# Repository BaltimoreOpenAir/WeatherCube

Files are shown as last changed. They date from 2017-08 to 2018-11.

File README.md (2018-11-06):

# WeatherCube
This repo provides code and schematics for the WeatherCube, an environmental monitoring platform used for the Baltimore OpenAir project. More info is on our project page at baltimoreopenair.github.io

#

# Hardware

## Circuit Boards 

### Component list:

1- The main board: It supports the microcontrollers. Its the brain of the device

2- Charging controller: provides power to the main board, charge up the battery with the solar panel

3- Lithium polymer battery: holds the power for the device

4- Analog front end board: holds the air quality sensors

5- Coin CR battery: powers the clock in case of loss of power

6- temperature sensor board: measures temperature and humidity in the tunnel

7- solar pannel: powers the unit

8- 4x air quality sensor: for N02,03,SO2 and H2S

9- 3X Molex picoblade cable assembly (2X 4 pins and 1X 5 pins): connects boards together

10- FTDI ttl/usb controller: allows to load code

11- ttl/usb ESP adapter: allows to connect the FTDI controller to load code in the ESP wifi chip

12- ttl/usb ATMEGA adapter: allows to connect the FTDI controller to load code in the ATMEGA microcontroller

## Electronic Assembly:

### Necessary equipment

1- Soldering iron

2- snips

3- box cutter

4- lead free rosin core solder of small gauge

5- a breadboard to serve as jig

6- A good multimeter for quality check

7- tweezers

9- a brush (such as a toothbrush)

10- methanol or rubbing alcohol

### Solder male header pins onto the main sensor board 

Use male 2.54mm (1/10th in) pitch headers. The headers come in 40 pins assembly, and will need to be sniped to the correct size. for this board you need 3x 7pins, 2x 2pins and 1x 1pin headers. You can use the ttl/usb adapter and/or a breadboard as jig to hold the pins in place at a right angle from the board. the pins should protrude in the front of the board and be soldered from the back. The positions of the headers are marked by yellow cirlces in the following image.

soldering of the 1/10th pitch headers on the main board (front of the board)

### Solder female header pins onto the Analog Front End (AFE) board
Use female 2mm pitch 2pin headers. You will need 12x 2pin headers. The pins should protrude from the front of the board and be soldered from the back. You can make a jig with 2mm male headers on a unassembled AFE PCB in order to correctly align the female headers. The pins should be scrubed with high proof methanol or other alcohol after soldering to avoid sensor bias. Resistance should be in excess of 40M Ohm between the reference and control electrode when the sensor is not mounted. The positions of the headers are marked by yellow cirlces in the following image. 

soldering of the 2mm pitch headers on the AFE board (front of the board)

### Solder the main sensor board to the solar charging board
The main board is to be soldered with the wires coming from the charge controller. If the battery is already soldered to the charge controller, you will be soldering live wires if the black and white wire connect. This does not constitute a danger of electrocution due to the low DC voltage but may lead to burining the charge controller if the board is shorted, and is a risk of fire. Therefore, extreme caution is necessary. The recommended order for soldering is red wire (5v) then the white wire ( enable wire). At this point, it is important to check that the red and white wires do not connect in any way, and trimming the wire ends may be a good idea. You can then solder the black wire (ground). Be careful not to short the circuit accidentally with the tip of your soldering iron. This closes the circuit. The positions of the wires are marked in the following image.

soldering of the wires on the main board

### Solder the usb/ttl adapters

The usb/ttl adapter need both male and female headers of 2.54mm pitch. The male headers are suposed to be protruding on the front of both boards and the female headers on the back. You may use a soldered main board as a jig to gold the female headers in place. To snip the female headers to the correct size, first count the numbers of pins you need and pull the next pin. You can then cut the header to sizer with a box cutter and shave the plastic for esthetics. The following image displat the positions of the male headers (yellow circles) and female headers (purple circles). For this, you need 2X 6pin male headers and 4X 7pin female headers. for the female headerds of the usb/ttl ESP adapter, you will need to pull some of the pins to fit in the soldering holes.

soldering headers on the usb/ttl atmega adapter

soldering headers on the usb/ttl esp adapter

### Plug things together
Follow the following figures to connect the differents component together. Do not forget to place the enable jumper on the main board once the code is loaded in

Connections on the main board

Connections on the Analog front end

## Sensors 
Read the calibration codes off the sensor QR codes using any QR code reader. Save these codes for later calibration. Then, plug in the sensors clockwise from the top left in the following order: O3, H2S, SO2, and NO2.

## Code loading

The software section describes the code that need to be loaded for the project. Here we describe the hardware setup necessary to communicate with the assembled device.

1- take the jumper off the enable pin on the main board.

2- connect the usb/ttl adapters on the wifi chip and on the atmega adapter.

3- make sure the FTDI controller jumper is on 3.3V

4- connect the FTDI controller with the usb cable to the computer. make sure that the ftdi controller has the proper driver installed. This can be done on windows by running this [executable](https://cdn.sparkfun.com/assets/learn_tutorials/7/4/CDM21228_Setup.exe).

5- connect the ftdi controller on the esp adapter.

6-  Using Arduino IDE, select the right com port and select the generic esp8266 in the tool section and load the esp8266 code. Make sure to modify the code with the target wifi credentials.

7- disconnect the FTDI controller and connect it to the atmega adapter. Using Arduino IDE, select the right com port and the arduino UNO board, load the code. You may have trouble to establish connections with the atmega when loading a code more than once. Restarting the computer seem to help in that case.

8- disconnect the adapters and put back the enable jumper. your weathercube is ready to be deployed!

## Hardware Quality checks

Using a multimeter one can check all the parameters of the device to check if all the component are working nominaly.

1- Check battery power: on the charge controller board, check the voltage potential at the soldered battery wires. The voltage should be between 2.8v and 4.2V. If close to 0V, check the battery wiring connections. If higher that 0.5V but lower than 2.8V, the battery is probably damaged. If higher than 4.2V the charge controller is damaged. If higher than 2.8V but lower than 3.3V, you should connect and charge the battery before usage using the mini usb port until reaching 4.2V.

2- Solar panel check: on the charge controller board, measure the voltage between the two wires of the solar panel. This should read between 4.1 and 4.4 V when the panel is exposed to direct sunlight. If the voltage is very low, there must be a problem in the wire connection on the solar panel. It the voltage is higher, the solar panel is runing in an open circuit, which means that either the battery is full, or if it is not, that the charge controller is damaged ore the solar panel wire connection on the charge controller is not good.

3- battery charge tester on the charge controller: click on the push button on the charge controller. If the charge controller leds do not light up and the battery voltage is superior to 2.8V this means that the charge controller is damaged.

4- main board power: check the voltage between the red and black wire of the charge controller on the main board. This should read close to 5V. if not the charge controller is damaged, or the connection of the white and black wire is not good. you can then check the volatege between vcc and ground on the board. it should read 3.3v when the enable pin is jumped and 0v else. If it reads 0V when the enable pin is in, the charge board is damaged or the connection is not good. if th reads 3.3V weither or not the jumper is on the enable pin, it means that the enable pin is shorted: check for solder residues that may short the two pins.

5- AFE board checks: the resistance between the 2mm pitch pins should be checked with a good multimeter (measurs resistance up to 40Mohm at least such as [this](https://www.amazon.com/dp/B000JKMTDM/ref=psdc_15707471_t2_B0050LVFS0)). Off the trio of headers for each sensor, the top one should have a resistance higher than 40Mohm when the sesor is not pluged in while the other should display no resistance. a 40Mohm reistance would bias the result by about 20ppb, which is the resolution of the sensor we are using. If the resistance is lower than that, pluck the plastic part of the pin and clean thourouly the plastic part and the pins with methanol. reassemble when dry and check again.

6- Fan check: in normal operation the fan should be runing every 15minutes for 30 seconds. If the fan does not run, you may try to run the fan by applying a 5v potential between its ground and live wires. Make sure you respect polarity. if the fan does not spin, it might be jammed. To unjam the fan, disasemble the air tunnel and manually check for fan rotation. take out any obstruction and check for rotation again. replace fan if need be.

7- Charging operation: check the battery volatage and note it up to 4 significant numbers. Put the weathercube in full sun for few hours. Without the main board unabled the unit should charge the battery at about .05V to .2V per hour in full unobstructed sun. The unit should still charge between .04V to .15V per hours when the unit is in operation. If not, the whole power circuit (solar panel, charging board and battery) might have to be recheched or replaced.

8- Com operation: when the cube is deployed in normal operation, you should recieve wifi communication once every day or as specified. if not, you may want to check first power then wifi communication credential in that unit.

# Software 

## Arduino Installation
Step zero is to install [Arduino](https://www.arduino.cc/). Note that in Linux, you may need need to launch Arduino using sudo priveleges. 

### 1. Add the ESP8266 board to Arduino. 

Follow: https://learn.sparkfun.com/tutorials/esp8266-thing-hookup-guide/installing-the-esp8266-arduino-addon 

### 2. Verify that you have the following libraries. If not, in Arduino, click Sketch--> Include Library --> Manage Libraries and search for the following libraries. When you find the library, click on it and an install button should appear. Click on this button to install. 
- Statistic
- SoftwareSerial
- Wire
- Adafruit_ADS1015
- EEPROM
- ESP8266WiFi

### 3. Download the following libraries for the Arduino Uno and save to your default Arduino library path (~/Arduino/libraries/): 
- [LMP91000](https://github.com/LinnesLab/LMP91000)
- [ClosedCube_HDC1080](https://github.com/closedcube/ClosedCube_HDC1080_Arduino/tree/master/src)
- [Adafruit_SHT31](https://github.com/adafruit/Adafruit_SHT31)
- [LowPower](https://github.com/rocketscream/Low-Power)
Note that on github, to download individual files you right-click on "raw" in the middle right and select "save file as". The files must be located in folders of the same name. 

### 4. Download the following files/libraries for the ESP8266 : 
Download and move the following files into the `AWSArduinoSDK` directory you just created: 
- [Esp8266AWSImplementations.h](https://github.com/daniele-salvagni/aws-sdk-esp8266/tree/master/src/esp8266)
- AmazonDynamoDBClient.h(https://github.com/daniele-salvagni/aws-sdk-esp8266/tree/master/src/common)
- AWSFoundationalTypes.h(https://github.com/daniele-salvagni/aws-sdk-esp8266/tree/master/src/common)

## AWS setup 
These instructions are courtesy Daniele Salvagni at https://github.com/daniele-salvagni/aws-sdk-esp8266/ 

### 1. Create an AWS account

Create an account at https://aws.amazon.com/. Note this requires a credit card but it's possible to be on AWS' free tier. You may also qualify for educational credits. Follow along steps 1 and 2 using the instructions in http://ncar.github.io/chords/aws.html . 

Then, create a user in the IAM managment console: https://docs.aws.amazon.com/IAM/latest/UserGuide/id_users_create.html#id_users_create_console
Get your awsKeyID and awsSecKey in the last step by going to IAM--> Users--> Security credentials. . 

### 2. Set up the DynamoDB Table

You will need to set up a DynamoDB table with the same name, hash key, and range key as in the sample you are using. These values are defined as constants in the sample, i.e. `HASH_KEY_NAME` and `TABLE_NAME`.

You can follow the steps below to get the tables set up with the right values:

* Log into the [AWS Console](http://console.aws.amazon.com/) and navigate to **DynamoDB**.
* Click on the "Create Table" button.
* Enter `ESP8266AWSDemo` as the *Table Name*, `id` as the primary *Partition Key*, and `timest` as the primary *Sort Key*. Be sure to mark *id* as *String* and *timest* as *Number*.
* Just one *Read Capacity Unit* and one *Write Capacity Unit* will be more than enough for this demo. Press create with these values.
* After the table has finished creating you are good to go, your ESP will take care about populating it.

### 3. Creating `keys.h` and `keys.cpp`

You will need to create and add `keys.h` and `keys.cpp` into the `AWSArduinoSDK` directory you made. Alternatively, if you want to use different access keys for every sketch you make, just put them inside your current sketch folder. These files define the `awsKeyID` and `awsSecKey` values used by the sketch, the files may be structured as following:

```
// keys.h
#ifndef KEYS_H_
#define KEYS_H_

extern const char* awsKeyID;  // Declare these variables to
extern const char* awsSecKey; // be accessible by the sketch
extern const char* pSSID; 
extern const char* pPassword; 
extern const char* SERIAL_ID;

#endif
```

```
// keys.cpp
#include "keys.h"

const char* awsKeyID = "YOUR AWS KEY ID HERE";
const char* awsSecKey = "YOUR AWS SECRET KEY HERE";
extern const char* pSSID = "YOUR WIFI NETWORK NAME HERE"; 
extern const char* pPassword = "YOUR PASSWORD HERE"; 
extern const char* SERIAL_ID = "ID NUMBER HERE";
```

*Do not share your AWS keys with anyone, it is reccomended to create a dedicated user with restricted permissions, do not use your root account. If you accidentally push your keys online disable them immediatly from the [AWS IAM console](https://console.aws.amazon.com/iam/home)*

## Programming 
### 1.  Bootload the boards using Atmel studio (if we've given you boards, we've already done this for you)
### 2. Load the Blink example sketch onto the ATMega selecting Arduino Uno as the board 
For this step, you could use any sketch onto the ATMega that doesn't tie up the serial lines, such as reset_esp.ino.
### 3. Edit the keys.h file from AWS setup step 3
### 4. Load esp_main sketch onto the ESP8266 
### 4. Load wxcube_main sketch onto the ATMega using the Uno settings

# Data 
### Data access through AWS Console
To view your data, log in to the [AWS Console](http://console.aws.amazon.com/) and navigate to **DynamoDB**. Click on "Tables" in the left hand menu, select your table and click on "Items". To download your table, first create a filter by selecting "filter". You can select for ids or for time. Note that ids are strings and time is a number such as '20170908000015'.  Click start search. When the search is complete, click "Actions" and select  "Download as CSV". 

### Command line/Python data access
Install and configure Boto3 in Python following the [documentation](https://boto3.readthedocs.io/en/latest/guide/quickstart.html#installation). 

The following sample code can be used to retrieve one sensor's data and turn it into a Pandas dataframe with a 'datetime' index. 

```
import pandas as pd
import boto3
from boto3.dynamodb.conditions import Key, Attr
dynamodb = boto3.resource('dynamodb')
table = dynamodb.Table('BaltimoreOpenAir2017')
sel_id = 1 # change this to the sensor id you are querying 
# the following will pull any data after September 8, 2017; change to your desired date
response = table.query(KeyConditionExpression=Key('id').eq(str(sel_id)) & Key('timest').gt(20170908000015)) 
df = pd.DataFrame(response['Items'])
# clean up the dataframe
df['timest'] = [pd.to_datetime(str(date)[:-4], format = '%Y%m%d%H%M') for date in df['timest']]
# read in batteryAV to get the time
df[['something', 'HourMinute', 'MonthDay', 'AV', 'drop'] ] = df['battAV'].str.split(',').apply(pd.Series)
# key in the calibration codes, m_o3, m_no2, m_so2, m_h2s
df[['O3_avg', 'O3_std']]   = df[['O3_avg', 'O3_std']].astype(float)/ m_o3)
df[['NO2_avg', 'NO2_std']] = df[['NO2_avg', 'NO2_std']].astype(float)/m_no2)
df[['SO2_avg', 'SO2_std']] = df[['SO2_avg', 'SO2_std']].astype(float)/m_so2)
df[['H2S_avg', 'H2S_std']] = df[['H2S_avg', 'H2S_std']].astype(float)/m_h2s)

# set up time index 
date_index = []
for date in df[['MonthDay', 'HourMinute']].values : 
    try: 
        if date[0] == '32767' : 
            date_index.append(np.nan)
        elif date[0] == '0' : 
            date_index.append(np.nan)
        else:
            date_index.append(pd.to_datetime('2017' +date[0]+date[1], format = '%Y%m%d%H%M'))
    except ValueError:  
        date_index.append(np.nan)
df['date_index'] = date_index
```

For an implementation of the code & a proposed calibration technique, see (https://github.com/BaltimoreOpenAir/BOAFieldEvaluation/blob/master/MDE_Beltsville_Analysis.ipynb).

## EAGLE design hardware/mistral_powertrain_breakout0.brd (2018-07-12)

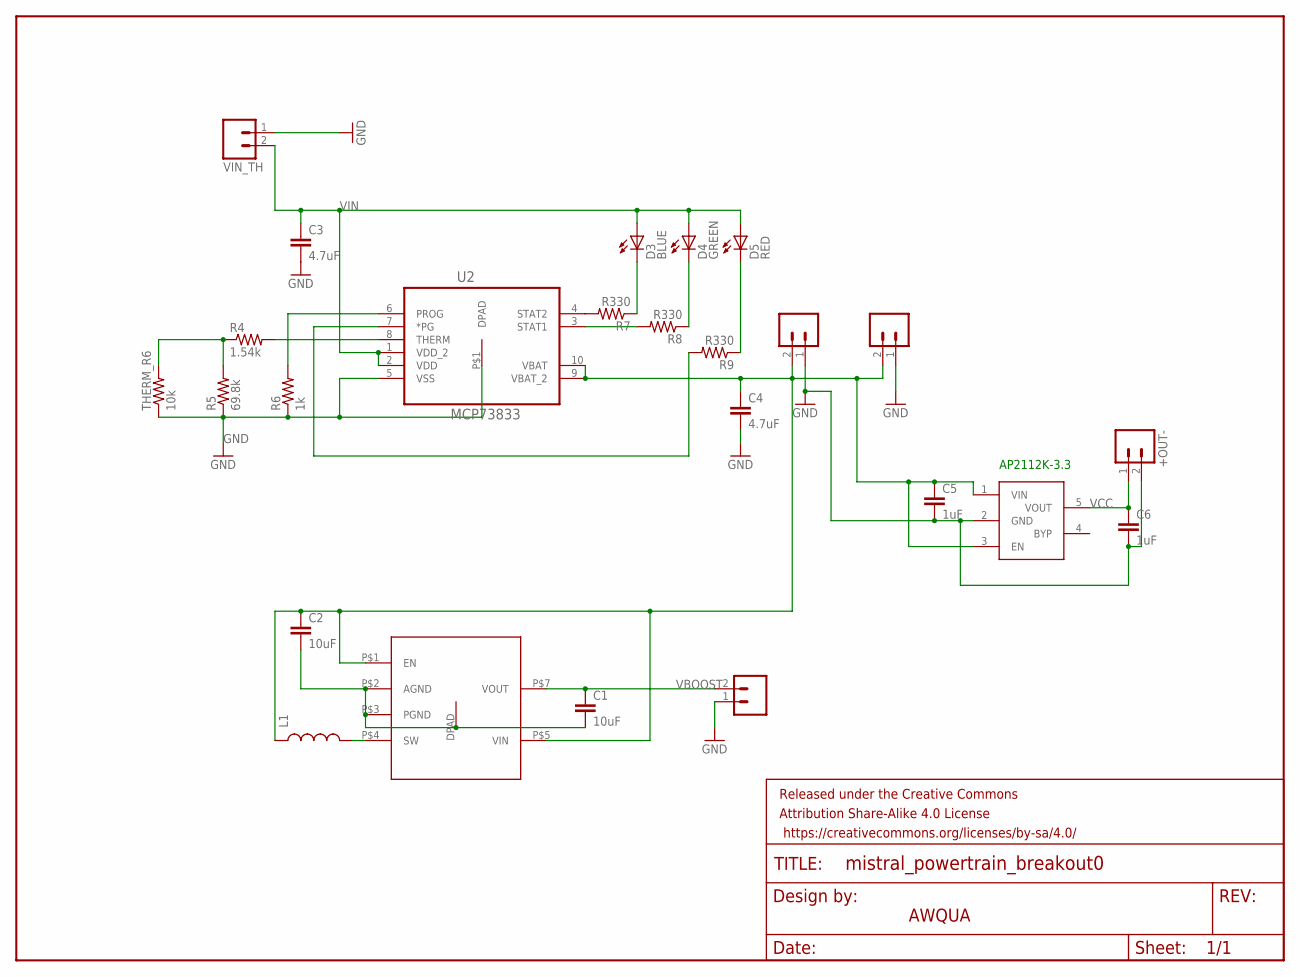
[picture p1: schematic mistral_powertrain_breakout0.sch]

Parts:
+OUT-: M02PTH; 1X02
C1, C2: 10uF; 0402-CAP
C3, C4: 4.7uF; 0402-CAP
C5, C6: 1uF; 0603-CAP
D3: BLUE; LED-0603
D4: GREEN; LED-0603
D5: RED; LED-0603
FRAME1: FRAME-LETTER; CREATIVE_COMMONS
JMP, JMP1: M02PTH; 1X02
JP7: LiPo Battery; JST-2-SMD
L1: INDUCTOR0805; 0805
R4: 1.54k; 0402-RES
R5: 69.8k; 0402-RES
R6: 1k; 0402-RES
R7, R8, R9: R330; 0402-RES
THERM_R6: 10k; 0402-RES
U2: MCP73833; SOP50P490X110-10N
U$1: DIO6605B
U$2: LP2985
VIN_TH: M02PTH; 1X02

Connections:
GND: +OUT-.2, C3.2, C4.2, C5.2, C6.2, JMP.1, JMP1.1, JP7.1, R5.1, R6.1, THERM_R6.1, U2.5 (VSS), U2.P$1 (DPAD), U$2.2 (GND), VIN_TH.1
unnamed: C1.2, C2.2, U$1.DPAD (DGND), U$1.P$2 (AGND), U$1.P$3 (PGND)
unnamed: L1.2, U$1.P$4 (SW)
unnamed: R4.2, U2.8 (THERM)
unnamed: R4.1, R5.2, THERM_R6.2
unnamed: R6.2, U2.6 (PROG)
unnamed: R7.2, U2.4 (STAT2)
unnamed: D3.C, R7.1
unnamed: R8.2, U2.3 (STAT1)
unnamed: D4.C, R8.1
unnamed: D5.C, R9.1
unnamed: R9.2, U2.7 (*PG)
VBAT: C2.1, C4.1, C5.1, JMP.2, JP7.2, L1.1, U2.9 (VBAT_2), U2.10 (VBAT), U$1.P$1 (EN), U$1.P$5 (VIN), U$2.1 (VIN), U$2.3 (EN)
VBOOST: C1.1, JMP1.2, U$1.P$7 (VOUT)
VCC: +OUT-.1, C6.1, U$2.5 (VOUT)
VIN: C3.1, D3.A, D4.A, D5.A, U2.1 (VDD_2), U2.2 (VDD), VIN_TH.2

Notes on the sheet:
AWQUA
AP2112K-3.3

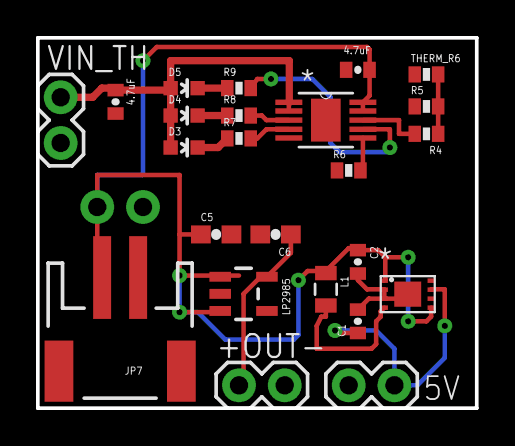
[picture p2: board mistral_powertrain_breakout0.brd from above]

Board: 2 copper layers, 24.4 x 20.6 mm, 26 parts (1 on the bottom side), 16 nets.

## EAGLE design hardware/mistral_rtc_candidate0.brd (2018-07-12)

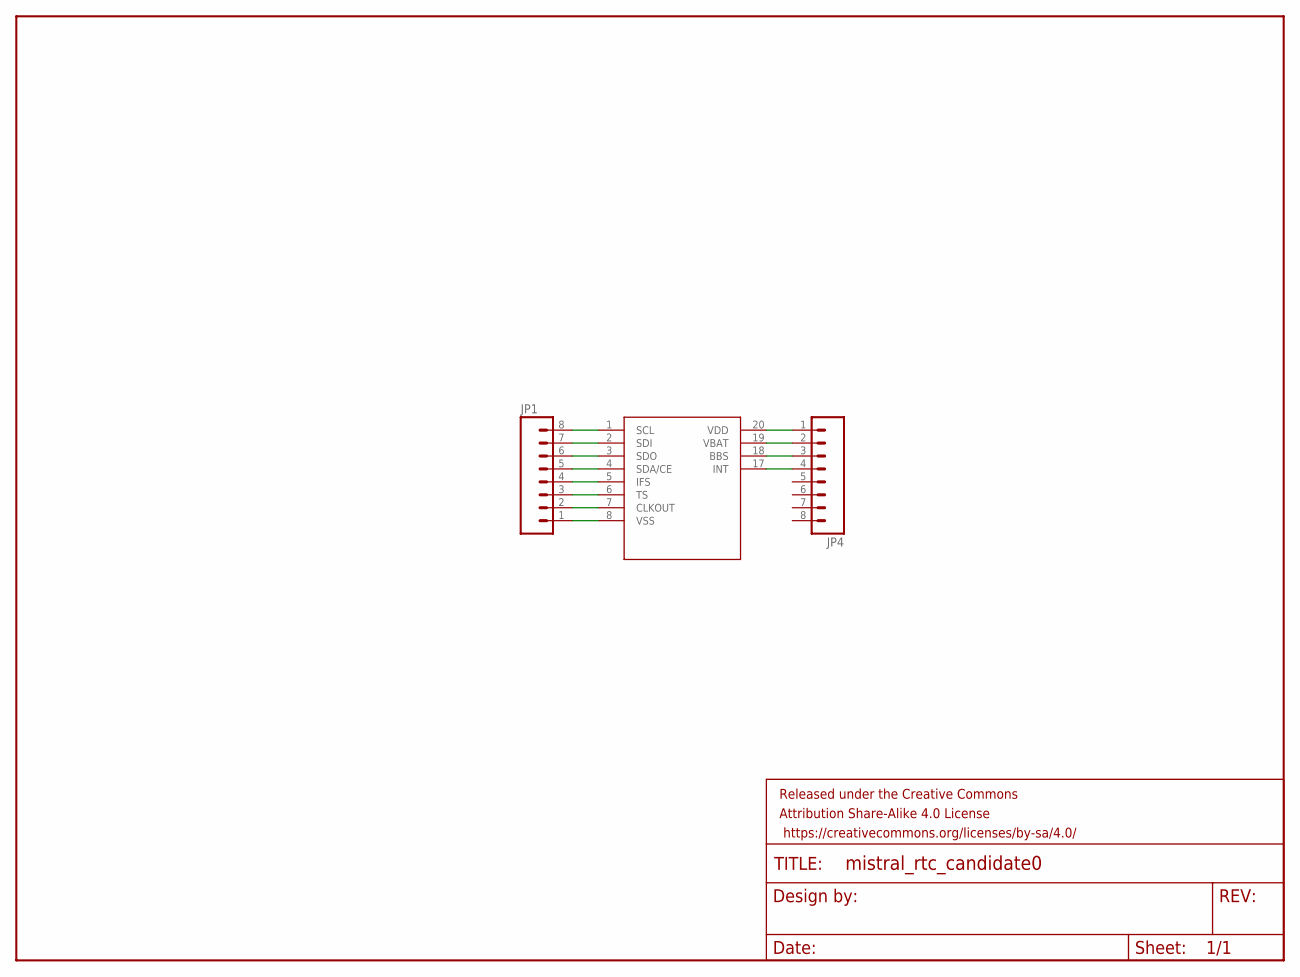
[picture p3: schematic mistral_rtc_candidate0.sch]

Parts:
FRAME1: FRAME-LETTER; CREATIVE_COMMONS
JP1, JP4: M08SILK_FEMALE_PTH; 1X08
U$1: PCF2129

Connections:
unnamed: JP1.1, U$1.8 (VSS)
unnamed: JP1.2, U$1.7 (CLKOUT)
unnamed: JP1.3, U$1.6 (TS)
unnamed: JP1.4, U$1.5 (IFS)
unnamed: JP1.5, U$1.4 (SDA/CE)
unnamed: JP1.6, U$1.3 (SDO)
unnamed: JP1.7, U$1.2 (SDI)
unnamed: JP1.8, U$1.1 (SCL)
unnamed: JP4.1, U$1.20 (VDD)
unnamed: JP4.2, U$1.19 (VBAT)
unnamed: JP4.3, U$1.18 (BBS)
unnamed: JP4.4, U$1.17 (INT)

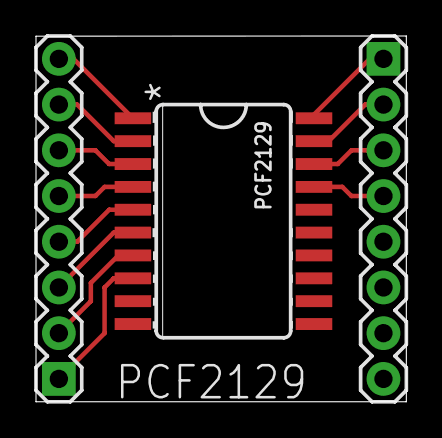
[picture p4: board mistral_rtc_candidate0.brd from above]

Board: 2 copper layers, 20.6 x 20.3 mm, 4 parts (0 on the bottom side), 12 nets.

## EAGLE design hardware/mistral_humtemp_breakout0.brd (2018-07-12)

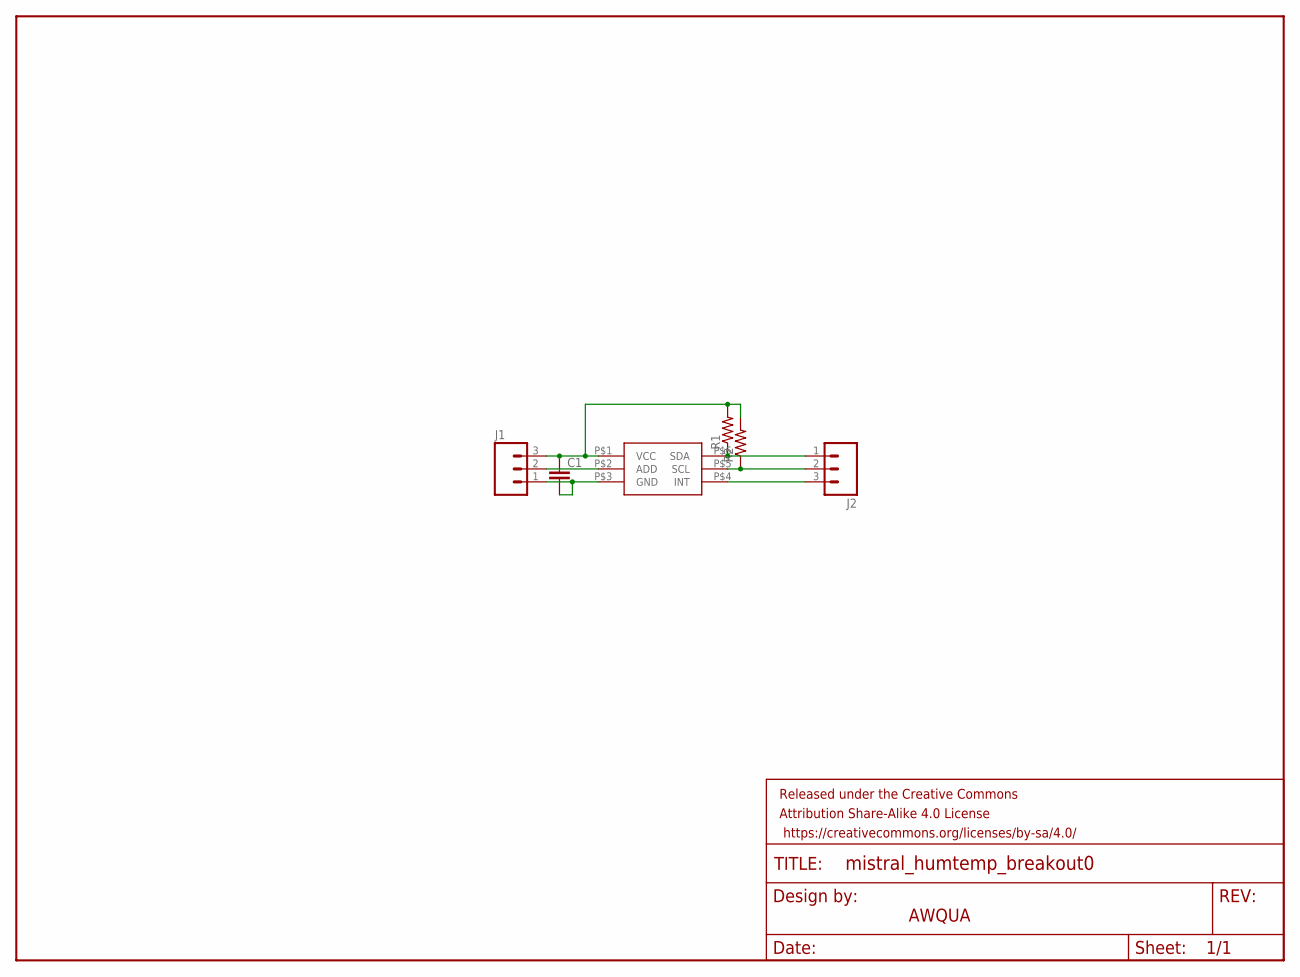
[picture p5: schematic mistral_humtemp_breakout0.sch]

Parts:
C1: CAP0603-CAP; 0603-CAP
FRAME1: FRAME-LETTER; CREATIVE_COMMONS
J1, J2: M03PTH; 1X03
R1, R2: RESISTOR0603-RES; 0603-RES
U$1: HDC2010

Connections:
ADD: J1.2, U$1.P$2 (ADD)
GND: C1.2, J1.1, U$1.P$3 (GND)
INT: J2.3, U$1.P$4 (INT)
SCL: J2.2, R2.1, U$1.P$5 (SCL)
SDA: J2.1, R1.1, U$1.P$6 (SDA)
VCC: C1.1, J1.3, R1.2, R2.2, U$1.P$1 (VCC)

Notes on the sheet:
AWQUA

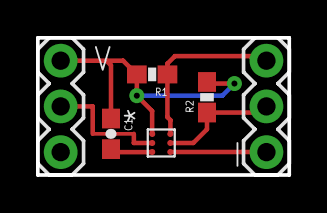
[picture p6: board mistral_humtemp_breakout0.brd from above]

Board: 2 copper layers, 14.0 x 7.6 mm, 7 parts (0 on the bottom side), 6 nets.

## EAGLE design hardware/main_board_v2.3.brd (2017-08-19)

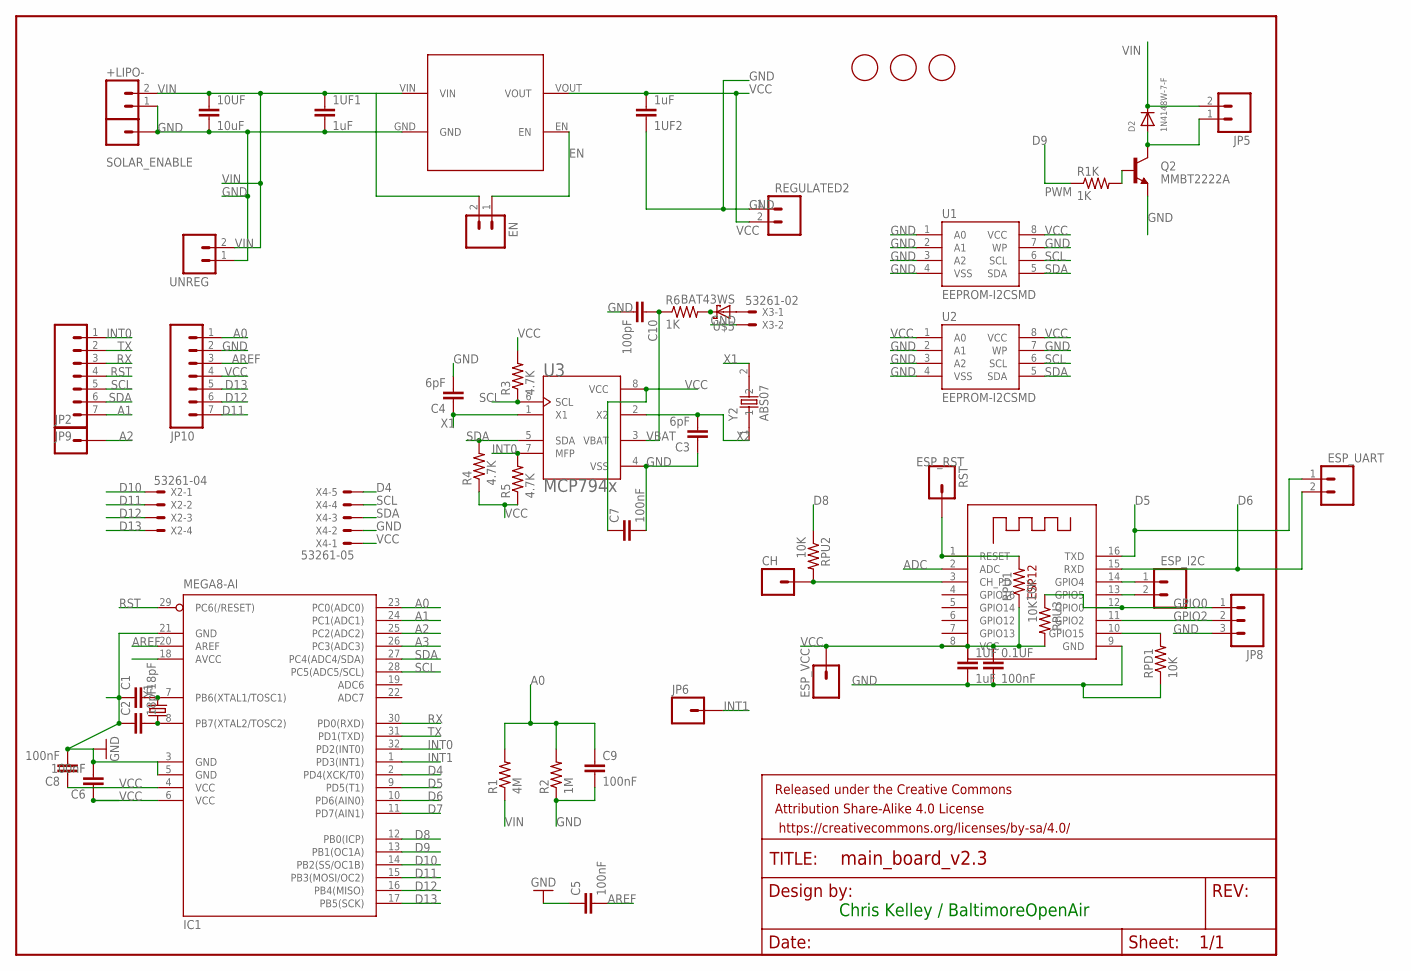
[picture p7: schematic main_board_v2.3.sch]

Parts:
0.1UF: 100nF; 0603-CAP
1UF, 1UF1, 1UF2: 1uF; 0603-CAP
10UF: 10uF; 0805
+LIPO-: M02PTH; 1X02
C1, C2: 18pF; 0603-CAP
C3, C4: 6pF; 0603-CAP
C5, C6, C7, C8, C9: 100nF; 0603-CAP
C10: 100pF; 0603-CAP
CH: M01PTH; 1X01
D2: 1N4148W-7-F; SOD-123
EN: M02PTH; 1X02
ESP_I2C: M02PTH; 1X02
ESP_UART: M02PTH; 1X02
ESP_VCC: M01PTH; 1X01
FRAME1: FRAME-LETTER; CREATIVE_COMMONS
IC1: MEGA8-AI; TQFP32-08
JP2, JP6: M01PTH; 1X01
JP5: M02-JST-2MM-SMT; JST-2-SMD
JP8: M03PTH; 1X03
JP9, JP10: M07; 1X07
Q2: MMBT2222A; SOT23-3
R1: 4M; 0603-RES
R1K, R6: 1K; 0603-RES
R2: 1M; 0603-RES
R3, R4, R5: 4.7K; 0603-RES
REGULATED2: M02PTH; 1X02
RPD1: 10K; 0603-RES
RPU1, RPU2, RPU3: 10K; 0603-RES
RST: M01PTH; 1X01
SOLAR_ENABLE: M01PTH; 1X01
U1, U2: EEPROM-I2CSMD; SO08
U3: MCP794x; SOIC127P600X175-8N
U$3, U$6, U$7: FIDUCIAL; FIDUCIAL_1MM
U$4: AP2112K; AP2112K-SOT23-5
U$5: BAT43WS
UNREG: M02PTH; 1X02
X1: ESP-12
X2: 53261-04
X3: 53261-02
X4: 53261-05
Y1: CRYSTAL5X3; CRYSTAL-SMD-5X3
Y2: ABS07; XTAL320X150X90

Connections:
A0: C9.1, IC1.23 (PC0(ADC0)), JP10.1, R1.2, R2.2
A1: IC1.24 (PC1(ADC1)), JP9.7
A2: IC1.25 (PC2(ADC2)), JP2.1
A3: IC1.26 (PC3(ADC3))
ADC: X1.2 (ADC)
AREF: C5.2, IC1.20 (AREF), JP10.3
CH_PD: CH.1, RPU2.2, X1.3 (CH_PD)
D4: IC1.2 (PD4(XCK/T0)), X4.5
D5: ESP_UART.1, IC1.9 (PD5(T1)), X1.16 (TXD)
D6: ESP_UART.2, IC1.10 (PD6(AIN0)), X1.15 (RXD)
D7: IC1.11 (PD7(AIN1))
D8: IC1.12 (PB0(ICP)), RPU2.1
D9: IC1.13 (PB1(OC1A)), R1K.1
D10: IC1.14 (PB2(SS/OC1B)), X2.1
D11: IC1.15 (PB3(MOSI/OC2)), JP10.7, X2.2
D12: IC1.16 (PB4(MISO)), JP10.6, X2.3
D13: IC1.17 (PB5(SCK)), JP10.5, X2.4
EN: EN.1, U$4.EN
ESP_RST: RPU1.2, RST.1, X1.1 (RESET)
GND: 0.1UF.2, 1UF.2, 1UF1.2, 1UF2.1, 10UF.2, +LIPO-.1, C1.1, C2.1, C3.1, C4.2, C5.1, C6.2, C7.2, C8.2, C9.2, C10.2, IC1.3 (GND), IC1.5 (GND), IC1.21 (GND), JP8.3, JP10.2, Q2.2 (E), R2.1, REGULATED2.1, RPD1.1, SOLAR_ENABLE.1, U1.1 (A0), U1.2 (A1), U1.3 (A2), U1.4 (VSS), U1.7 (WP), U2.2 (A1), U2.3 (A2), U2.4 (VSS), U2.7 (WP), U3.4 (VSS), U$4.GND, UNREG.1, X1.9 (GND), X3.2, X4.2
GPIO0: JP8.1, RPU3.1, X1.12 (GPIO0)
GPIO2: JP8.2, X1.11 (GPIO2)
GPIO15: RPD1.2, X1.10 (GPIO15)
INT0: IC1.32 (PD2(INT0)), JP9.1, R5.2, U3.7 (MFP)
INT1: IC1.1 (PD3(INT1)), JP6.1
unnamed: D2.A, JP5.1 (2), Q2.3 (C)
unnamed: U$5.PIN1 (C), X3.1
unnamed: ESP_I2C.1, X1.14 (GPIO4)
unnamed: R6.2, U$5.PIN2 (A)
unnamed: ESP_I2C.2, X1.13 (GPIO5)
PWM: Q2.1 (B), R1K.2
Q1: C2.2, IC1.8 (PB7(XTAL2/TOSC2)), Y1.1
Q2: C1.2, IC1.7 (PB6(XTAL1/TOSC1)), Y1.3 (2)
RST: IC1.29 (PC6(/RESET)), JP9.4
RX: IC1.30 (PD0(RXD)), JP9.3
SCL: IC1.28 (PC5(ADC5/SCL)), JP9.5, R3.1, U1.6 (SCL), U2.6 (SCL), U3.6 (SCL), X4.4
SDA: IC1.27 (PC4(ADC4/SDA)), JP9.6, R4.2, U1.5 (SDA), U2.5 (SDA), U3.5 (SDA), X4.3
TX: IC1.31 (PD1(TXD)), JP9.2
VBAT: C10.1, R6.1, U3.3 (VBAT)
VCC: 0.1UF.1, 1UF.1, 1UF2.2, C6.1, C7.1, C8.1, ESP_VCC.1, IC1.4 (VCC), IC1.6 (VCC), IC1.18 (AVCC), JP10.4, R3.2, R4.1, R5.1, REGULATED2.2, RPU1.1, RPU3.2, U1.8 (VCC), U2.1 (A0), U2.8 (VCC), U3.8 (VCC), U$4.VOUT, X1.8 (VCC), X4.1
VIN: 1UF1.1, 10UF.1, +LIPO-.2, D2.C, EN.2, JP5.2 (1), R1.1, U$4.VIN, UNREG.2
X1: C4.1, U3.1 (X1), Y2.2
X2: C3.2, U3.2 (X2), Y2.1

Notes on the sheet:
Chris Kelley / BaltimoreOpenAir

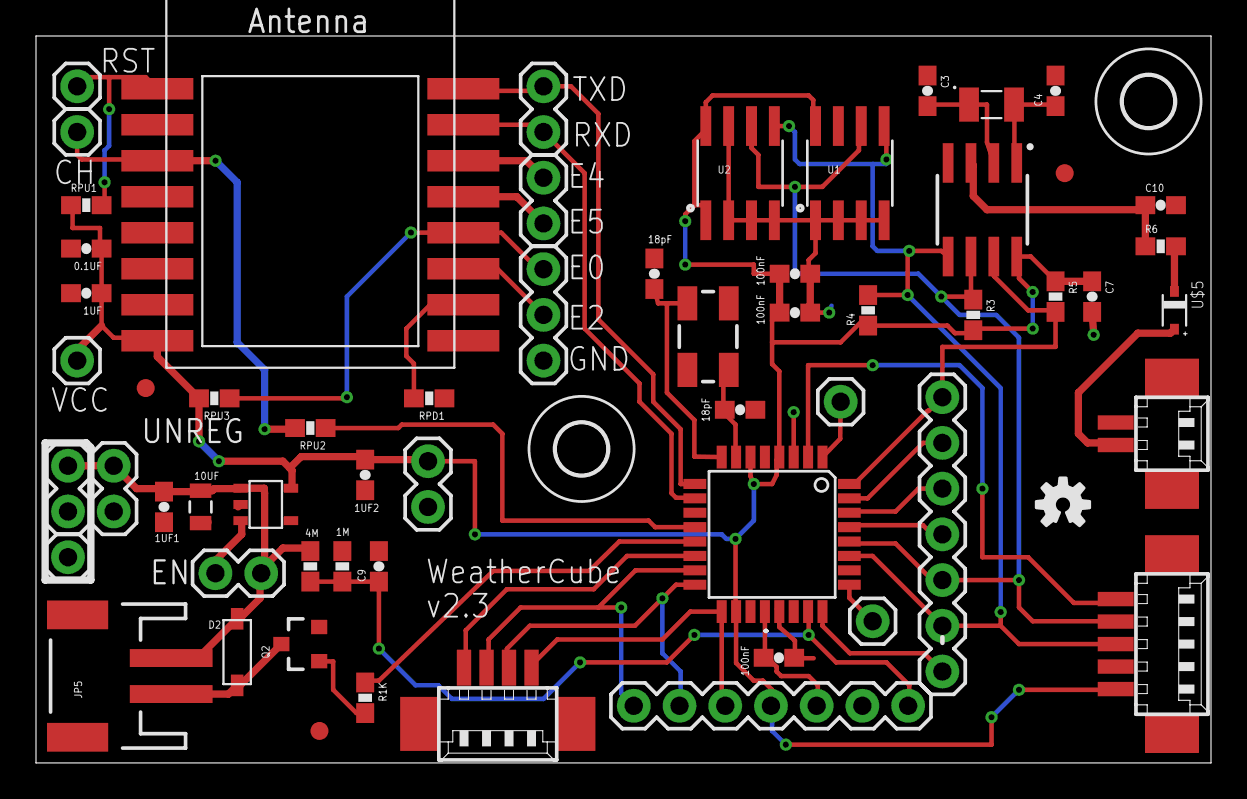
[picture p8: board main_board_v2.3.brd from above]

Board: 2 copper layers, 65.3 x 40.4 mm, 64 parts (1 on the bottom side), 40 nets.

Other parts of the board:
U$1, U$9: 2,8
U$2, U$8: OSHW-LOGO-S

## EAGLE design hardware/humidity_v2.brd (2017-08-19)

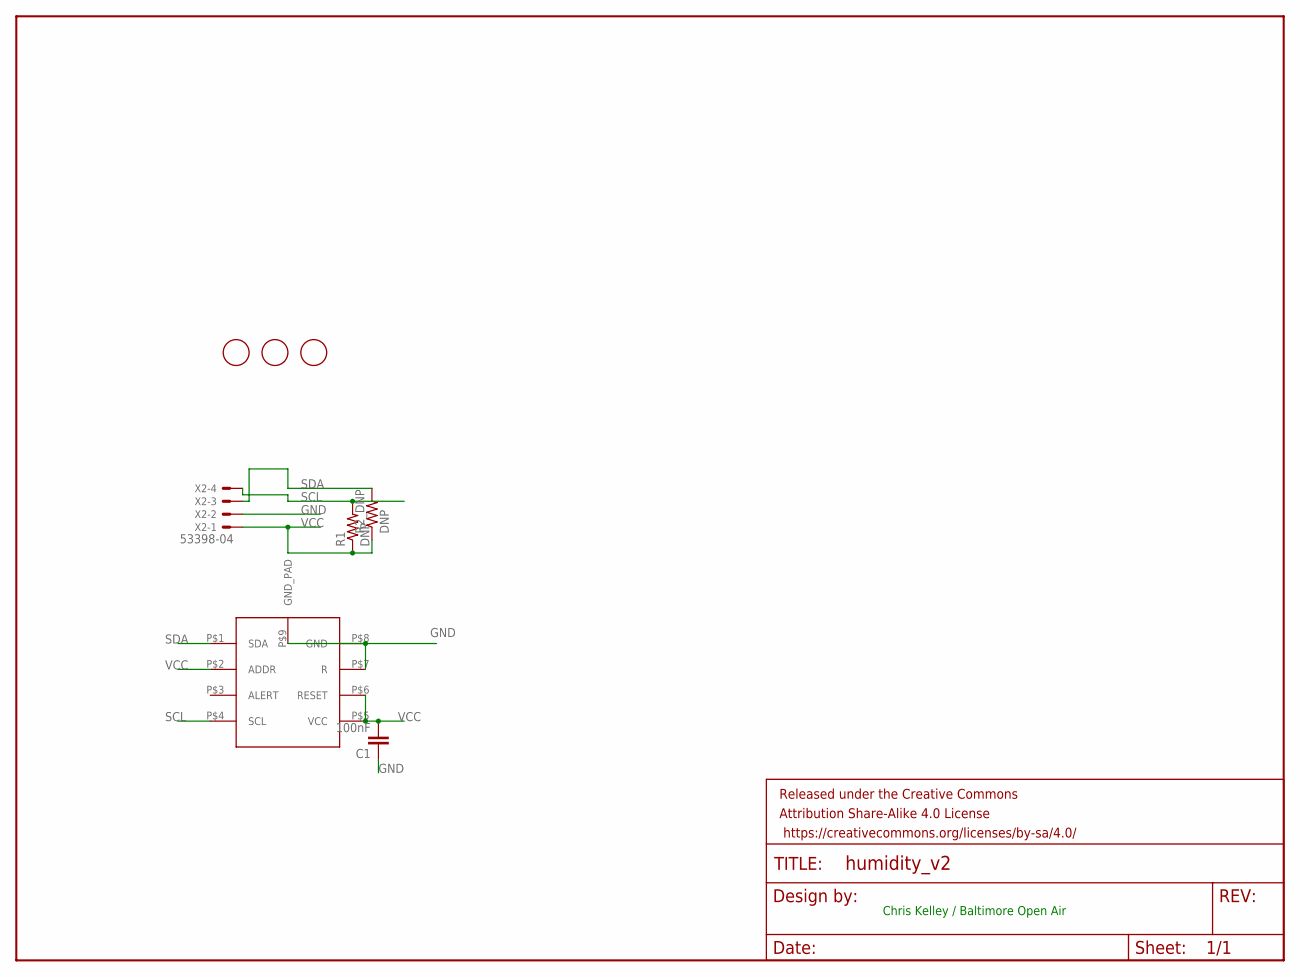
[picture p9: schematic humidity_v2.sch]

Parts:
C1: 100nF; 0603-CAP
FRAME1: FRAME-LETTER; CREATIVE_COMMONS
R1, R2_DNP: DNP; 0603-RES
U$1: SHT31-D
U$3, U$6, U$7: FIDUCIAL; FIDUCIAL_1MM
X2: 53398-04

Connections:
GND: C1.1, U$1.P$7 (R), U$1.P$8 (GND), U$1.P$9 (GND_PAD), X2.2
SCL: R1.2, U$1.P$4 (SCL), X2.4
SDA: R2_DNP.2, U$1.P$1 (SDA), X2.3
VCC: C1.2, R1.1, R2_DNP.1, U$1.P$2 (ADDR), U$1.P$5 (VCC), U$1.P$6 (RESET), X2.1

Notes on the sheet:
Chris Kelley / Baltimore Open Air

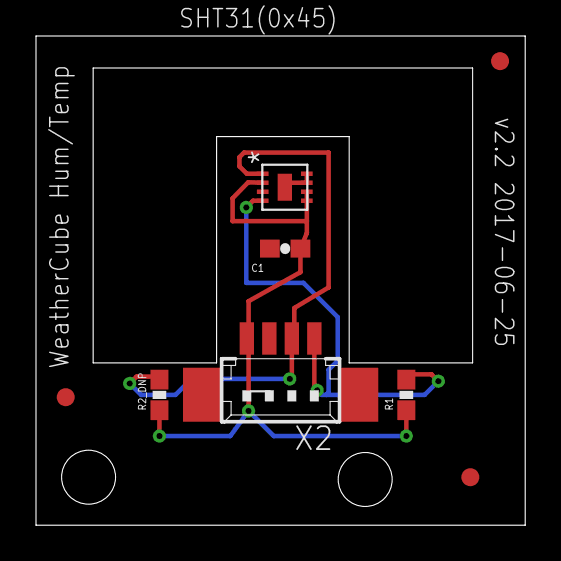
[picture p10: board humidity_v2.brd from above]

Board: 2 copper layers, 27.2 x 27.2 mm, 9 parts (0 on the bottom side), 4 nets.

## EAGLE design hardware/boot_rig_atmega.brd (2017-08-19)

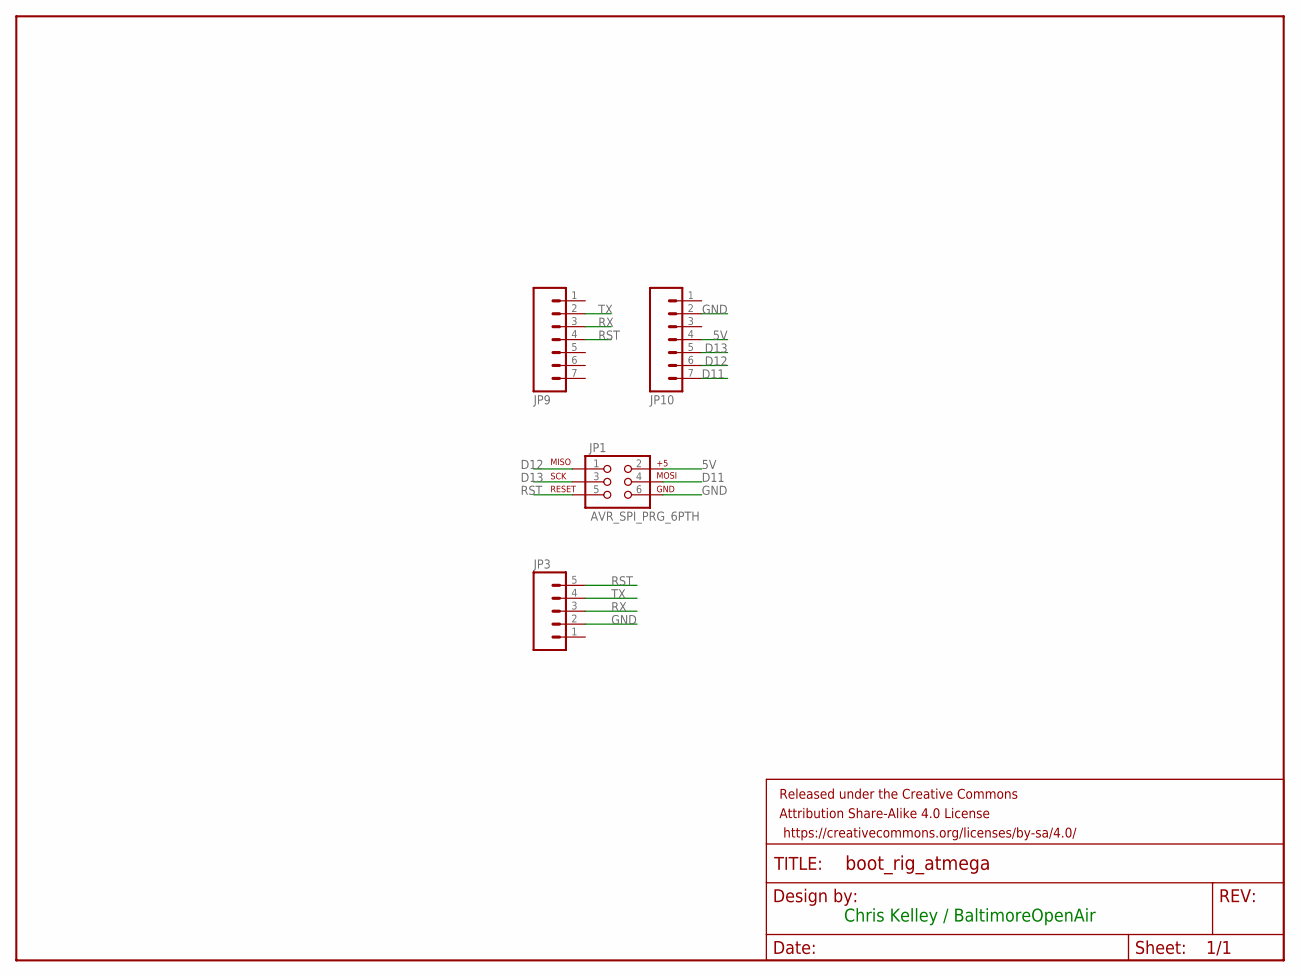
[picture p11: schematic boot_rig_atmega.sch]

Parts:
FRAME1: FRAME-LETTER; CREATIVE_COMMONS
JP1: AVR_SPI_PRG_6PTH; 2X3
JP3: M05PTH; 1X05
JP9, JP10: M07; 1X07

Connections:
5V: JP1.2, JP3.1, JP10.4
D11: JP1.4, JP10.7
D12: JP1.1, JP10.6
D13: JP1.3, JP10.5
GND: JP1.6, JP3.2, JP10.2
RST: JP1.5, JP3.5, JP9.4
RX: JP3.3, JP9.3
TX: JP3.4, JP9.2

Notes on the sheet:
Chris Kelley / BaltimoreOpenAir

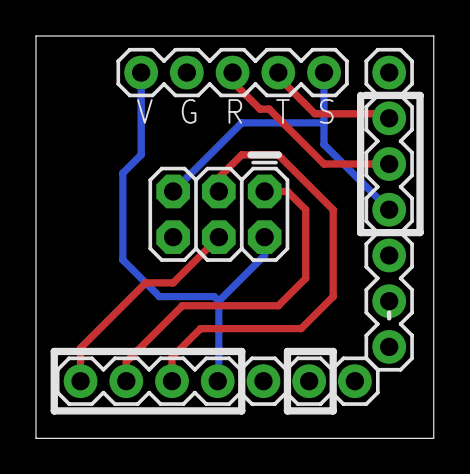
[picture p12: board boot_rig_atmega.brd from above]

Board: 2 copper layers, 22.1 x 22.4 mm, 5 parts (0 on the bottom side), 8 nets.

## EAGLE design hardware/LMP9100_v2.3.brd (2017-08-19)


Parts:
C1, C1_100NF1, C1_100NF2, C1_100NF3, C1_100NF4, C1_100NF5, C2, C3, C4, C100NF, C100NF1: 100nF; 0603-CAP
C22NF: 22nF; 0603-CAP
FRAME1: FRAME-LETTER; CREATIVE_COMMONS
R1_DNP, R2_DNP: DNP; 0603-RES
R3, R4, R5, R6: 49.9; 0603-RES
TIA.C, TIA.C1, TIA.C2, TIA.C3: CAP0603-CAP; 0603-CAP
TIA.R, TIA.R1, TIA.R2, TIA.R3: 499K; 0603-RES
U1: ADS1115; MSOP10
U2: LM4120; SOT95P284X122-5N
U3, U4, U5, U6: LMP91000
U$1, U$6, U$7: FIDUCIAL; FIDUCIAL_1MM
U$2: SHT31-D
U$3: HDC1080; WSON-6-PAD
U$4, U$5, U$8, U$9: SPEC-SENSOR
U$10, U$11: MCP6042-E/SN; SOIC127P600X175-8N
X1, X3: 53261-04
X2: 53261-05

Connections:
ADC1: U1.4 (AIN0), U$10.1 (VOUTA), U$10.2 (VINA-)
ADC2: U1.5 (AIN1), U$10.6 (VINB-), U$10.7 (VOUTB)
ADC3: U1.6 (AIN2), U$11.1 (VOUTA), U$11.2 (VINA-)
ADC4: U1.7 (AIN3), U$11.6 (VINB-), U$11.7 (VOUTB)
CE1: R6.2, U6.14 (CE)
CE2: R4.2, U5.14 (CE)
CE3: R3.2, U4.14 (CE)
CE4: R5.2, U3.14 (CE)
EN: U2.3 (EN), X2.1
GND: C1.2, C1_100NF1.2, C1_100NF2.1, C1_100NF3.1, C1_100NF4.1, C1_100NF5.1, C2.2, C3.2, C4.2, C22NF.2, C100NF.2, C100NF1.1, U1.3 (VSS), U2.2 (GND), U3.1 (DGND), U3.7 (AGND), U3.DAP, U4.1 (DGND), U4.7 (AGND), U4.DAP, U5.1 (DGND), U5.7 (AGND), U5.DAP, U6.1 (DGND), U6.7 (AGND), U6.DAP, U$2.P$2 (ADDR), U$2.P$7 (R), U$2.P$8 (GND), U$2.P$9 (GND_PAD), U$3.2 (GND), U$4.NC, U$4.NC2, U$5.NC, U$5.NC2, U$8.NC, U$8.NC2, U$9.NC, U$9.NC2, U$10.4 (VSS), U$11.4 (VSS), X2.4, X3.3
unnamed: R5.1, U$4.CE
unnamed: R3.1, U$5.CE
unnamed: R4.1, U$8.CE
unnamed: R6.1, U$9.CE
OE1: U6.2 (MENB), X1.4
OE2: U5.2 (MENB), X1.3
OE3: U4.2 (MENB), X1.2
OE4: U3.2 (MENB), X1.1
RDY: U1.2 (ALERT/RDY)
RE1: U6.13 (RE), U$9.RE
RE2: U5.13 (RE), U$8.RE
RE3: U4.13 (RE), U$5.RE
RE4: U3.13 (RE), U$4.RE
SCL: R1_DNP.1, U1.10 (SCL), U3.3 (SCL), U4.3 (SCL), U5.3 (SCL), U6.3 (SCL), U$2.P$4 (SCL), U$3.6 (SCL), X2.2, X3.1
SDA: R2_DNP.1, U1.9 (SDA), U3.4 (SDA), U4.4 (SDA), U5.4 (SDA), U6.4 (SDA), U$2.P$1 (SDA), U$3.1 (SDA), X2.3, X3.2
TIA1: TIA.C.1, TIA.R.2, U3.10 (C1)
TIA2: TIA.C.2, TIA.R.1, U3.9 (C2)
TIA3: TIA.C1.1, TIA.R1.2, U4.10 (C1)
TIA4: TIA.C1.2, TIA.R1.1, U4.9 (C2)
TIA5: TIA.C2.1, TIA.R2.2, U5.10 (C1)
TIA6: TIA.C2.2, TIA.R2.1, U5.9 (C2)
TIA7: TIA.C3.1, TIA.R3.2, U6.10 (C1)
TIA8: TIA.C3.2, TIA.R3.1, U6.9 (C2)
VCC: C1.1, C1_100NF1.1, C1_100NF2.2, C1_100NF3.2, C1_100NF4.2, C1_100NF5.2, C2.1, C3.1, C4.1, C100NF.1, C100NF1.2, R1_DNP.2, R2_DNP.2, U1.1 (ADDR), U1.8 (VDD), U2.4 (VIN), U3.6 (VDD), U4.6 (VDD), U5.6 (VDD), U6.6 (VDD), U$2.P$5 (VCC), U$2.P$6 (RESET), U$3.5 (VDD), U$10.8 (VDD), U$11.8 (VDD), X2.5, X3.4
VOUT1: U6.8 (VOUT), U$10.3 (VINA+)
VOUT2: U5.8 (VOUT), U$10.5 (VINB+)
VOUT3: U4.8 (VOUT), U$11.3 (VINA+)
VOUT4: U3.8 (VOUT), U$11.5 (VINB+)
VREF: C22NF.1, U2.5 (VOUT), U3.11 (VREF), U4.11 (VREF), U5.11 (VREF), U6.11 (VREF)
WE1: U6.12 (WE), U$9.WE, U$9.WE2
WE2: U5.12 (WE), U$8.WE, U$8.WE2
WE3: U4.12 (WE), U$5.WE, U$5.WE2
WE4: U3.12 (WE), U$4.WE, U$4.WE2

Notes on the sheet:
Chris Kelley / Baltimore Open Air


Board: 2 copper layers, 76.2 x 50.8 mm, 47 parts (0 on the bottom side), 42 nets.

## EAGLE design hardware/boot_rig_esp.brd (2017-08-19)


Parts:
CH: M01PTH; 1X01
ESP_UART: M02PTH; 1X02
ESP_VCC: M01PTH; 1X01
FRAME1: FRAME-LETTER; CREATIVE_COMMONS
JP4: M06SILK_FEMALE_PTH; 1X06
JP8: M03PTH; 1X03
RST: M01PTH; 1X01

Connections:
3V3: CH.1, ESP_VCC.1, JP4.2, JP8.2
ESP_RST: JP4.3, RST.1
GND: JP4.4, JP8.1, JP8.3
RXE: ESP_UART.2, JP4.5
TXE: ESP_UART.1, JP4.6

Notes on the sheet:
Chris Kelley / BaltimoreOpenAir


Board: 2 copper layers, 30.2 x 20.3 mm, 7 parts (0 on the bottom side), 5 nets.

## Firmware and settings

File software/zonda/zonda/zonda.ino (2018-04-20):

//----------------PREAMBLE-----------------
#define SERIAL_ID 17
#define GAIN_INDEX 2  //defines ADC range -- 1 for 3.3V, [2 for 2.048V], 3 for 1.024V
#define MV_RATIO 0.0625
#define ADC_GAIN GAIN_TWO
#define DEBUG_MODE 0
#define DO_SETUP_TEST_POST false
#define STAT_COUNT 10
#define ADC_CHANNEL_COUNT 4
#define FREQUENCY 2000// sampling frequency in ms
#define PM true
#define SD_CS   10
#define PMS_SET A2
#define PMS_RESET A1
#define HW_BAUD 57600
//#define ESP_BAUD 9600
#define PMS_BAUD 9600
#define MAX_MESSAGE_LENGTH 120

#define start_second 0
#define start_minute 59
#define start_hour 21
#define start_day_of_week 5 //Sunday is 0, Saturday 7
#define start_day 13
#define start_month 4
#define start_year 18

//bool _reset = false; // whether to reset eeprom; always rerun
//----------------libraries-----------------
#include <Statistic.h>
#include <SoftwareSerial.h>
#include <Wire.h>
#include <Adafruit_ADS1015.h>
#include "LMP91000.h"
#include "ClosedCube_HDC1080.h"
#include "Adafruit_SHT31.h"
#include <EEPROM.h>
#include "LowPower.h"
#include <SPI.h>
#include <SD.h>

//#include "keys.h" // wifi passwords, amazon table details, serial id

//--------------- definitions-----------------
#define SEND_HOUR 13
#define FAN_INTERVAL 30000//30000
//#define READ_INTERVAL 180//180000//60000 // change for debug
//#define SLEEP_INTERVAL 600 //600000
#define RTC_ADDR 0x6F
#define RTC_TS_BITS 7
#define TIME_REG 0x00
//#define EEP0 0x50    //Address of 24LC256 eeprom chip
//#define EEP1 0x51    //Address of 24LC256 eeprom chip

#define ID_LOCATION 0 // where we save the id
#define CHECK_SETUP_INDEX 2 // where we save whether or not we've run the do_once setup functions, including setting id and setting clock
#define CHECK_SEND_LOCATION 4// where we save if the data successfully send 
#define LOOP_COUNTER_LOCATION 5 // where we log the number of data points not sent, or loop_counter
//#define EEP_WRITE_LOCATION_INDEX 6// where we log where the counter is; keep rolling it over to conserve lifetime of eeprom memory
//#define START_WRITE_LOCATION 64 // 2nd page
//#define MAX_MESSAGE_LENGTH 25

#define VDIV 5.02   //voltage divider: (1 + 4.02) / 1
#define VREF 1.1    //value of ATMega328 internal reference voltage
#define VREF_EN 4
#define WIFI_EN 8
#define FAN_EN 9
#define VOLT A0

// numeric code to index the array LMP91000
#define CO    0
//#define EtOH  1
//#define H2S   2
//#define SO2   3
//#define NO2   4
#define O3    1
#define IAQ   2
#define RESP  3

#define HDC_ADDRESS 0x40

#define PMS_DATA_INDEX 16
#define DATA_ARRAY_SIZE 32  //16 for AFE, 16 for PMS
//#define EEPROM_BLOCKSIZE 36
#define TOTAL_MEASUREMENT_TIME 1 // In minutes
#define SLEEP_MINUTES 0//112
#define MAX_POST_TRIES 10


//int gain_index = GAIN_INDEX;
//float mv_adc_ratio = 0.0;
//adsGain_t gain[6] = {GAIN_TWOTHIRDS, GAIN_ONE, GAIN_TWO, GAIN_FOUR, GAIN_EIGHT, GAIN_SIXTEEN};
//float mv_ratios[6] = {0.1875, 0.125, 0.0625, 0.03125, 0.015625, 0.0078125};
adsGain_t adc_pga_gain;

Adafruit_SHT31 sht31 = Adafruit_SHT31();
//Adafruit_SHT31 sht32 = Adafruit_SHT31();
ClosedCube_HDC1080 hdc1080;
LMP91000 lmp91000;
Adafruit_ADS1115 ads(0x49);

// initialize wifi serial connection
//SoftwareSerial esp(5, 6); // RX, TX
SoftwareSerial pms(3, 7);

//From D-ULPSM Rev 0.3 LMP91000 Settings //need to set TIACN register, REFCN register, MODECN register
// this is a 2-d array because the settings need to be split between different bytes
int LMP91000_settings[4][2] = {
  {LMP91000_TIA_GAIN_EXT | LMP91000_RLOAD_50OHM, LMP91000_REF_SOURCE_EXT | LMP91000_INT_Z_20PCT | LMP91000_BIAS_SIGN_POS | LMP91000_BIAS_1PCT},  //CO
  //{LMP91000_TIA_GAIN_EXT | LMP91000_RLOAD_50OHM, LMP91000_REF_SOURCE_EXT | LMP91000_INT_Z_20PCT | LMP91000_BIAS_SIGN_POS | LMP91000_BIAS_4PCT}, //EtOH
  //{LMP91000_TIA_GAIN_EXT | LMP91000_RLOAD_50OHM, LMP91000_REF_SOURCE_EXT | LMP91000_INT_Z_20PCT | LMP91000_BIAS_SIGN_POS | LMP91000_BIAS_0PCT},  //H2S
  //{LMP91000_TIA_GAIN_EXT | LMP91000_RLOAD_50OHM, LMP91000_REF_SOURCE_EXT | LMP91000_INT_Z_20PCT | LMP91000_BIAS_SIGN_POS | LMP91000_BIAS_10PCT}, //SO2
  //{LMP91000_TIA_GAIN_EXT | LMP91000_RLOAD_50OHM, LMP91000_REF_SOURCE_EXT | LMP91000_INT_Z_50PCT | LMP91000_BIAS_SIGN_NEG | LMP91000_BIAS_10PCT}, //NO2  //INT_Z 20
  {LMP91000_TIA_GAIN_EXT | LMP91000_RLOAD_50OHM, LMP91000_REF_SOURCE_EXT | LMP91000_INT_Z_50PCT | LMP91000_BIAS_SIGN_NEG | LMP91000_BIAS_1PCT},  //O3   //INT_Z 20
  {LMP91000_TIA_GAIN_EXT | LMP91000_RLOAD_50OHM, LMP91000_REF_SOURCE_EXT | LMP91000_INT_Z_20PCT | LMP91000_BIAS_SIGN_POS | LMP91000_BIAS_8PCT},  //IAQ
  {LMP91000_TIA_GAIN_EXT | LMP91000_RLOAD_50OHM, LMP91000_REF_SOURCE_EXT | LMP91000_INT_Z_50PCT | LMP91000_BIAS_SIGN_NEG | LMP91000_BIAS_10PCT}  //RESP
};
int MODECN_DEFAULT = LMP91000_FET_SHORT_DISABLED | LMP91000_OP_MODE_AMPEROMETRIC;

// declaring instances of objects in the statistic class
Statistic stat[10];

char inbyte;
//byte cbuf[MAX_MESSAGE_LENGTH];
char* _test;

long post_index = 0;
bool running_fan = true;
bool debug_set_rtc = false; // run the clock debug mode, sets clock and prints it
bool fan_on;
long read_interval, fan_interval;
bool immediate_run = false;
bool debug_run = false;
//int reading_location = 10;
int data_array[DATA_ARRAY_SIZE];
int loop_counter = 0;
//int loop_minimum = 96;
int eeprom_write_location = 64;
int device;
byte integer_time[RTC_TS_BITS]; // what we'll store time array in
//char types[] = {"oanbschdtrefgivHmN"};

int afe_note_code = -9999, pms_note_code = -9999;
bool logfile_error = false;
//----------------------------------------------------------------------------------------
//----------------------------------------------------------------------------------------

void setup()
{
  Serial.begin(HW_BAUD);
  Serial.println(F("Starting setup..."));

  //--------------------pin stuff----------------------
  analogReference(INTERNAL);
  pinMode(VOLT, INPUT);
  pinMode(VREF_EN, OUTPUT);
  pinMode(13, OUTPUT);
  pinMode(12, OUTPUT);
  pinMode(11, OUTPUT);
  pinMode(10, OUTPUT);
  pinMode(WIFI_EN, OUTPUT);
  pinMode(FAN_EN, OUTPUT);
  pinMode(PMS_SET, OUTPUT);
  pinMode(PMS_RESET, OUTPUT);
  pinMode(SD_CS, OUTPUT);

  digitalWrite(VREF_EN, LOW);
  digitalWrite(FAN_EN, LOW);
  digitalWrite(PMS_SET, HIGH);
  digitalWrite(PMS_RESET, HIGH);
  digitalWrite(WIFI_EN, LOW);
  Serial.println(F("finished pin setup"));
  delay(100);

  //esp.begin(ESP_BAUD);
  pms.begin(PMS_BAUD);
  Wire.begin();

   //----------------SD card-------------------------
  if (!SD.begin(SD_CS)) {
    logfile_error = true;
    Serial.println(F("init failed!"));
  }
  else{
    Serial.println(F("init done."));
    /*File logfile = SD.open(F("logfile.txt"));
    if (logfile) {
      while (logfile.available()) {
        Serial.write(logfile.read());
      }
      logfile.close();
    } else {
      Serial.println("error opening logfile.txt");
    }*/
  }
  delay(100);

  //----------------set adc/afe stuff------------------
  //set_adc_gain(gain_index);
  ads.setGain(ADC_GAIN);
  ads.begin();
  set_afe(0, CO, 1); // (pin number, sensor type, index#)
  set_afe(1, O3, 2);
  set_afe(2, IAQ, 3);
  set_afe(3, RESP, 4);
  delay(50);

  //----------------read (/set) timestamp--------------
  
  //rtc_write_date(start_second, start_minute, start_hour, start_day_of_week, start_day, start_month, start_year); //uncomment to manually update RTC timestamp
  rtc_read_timestamp(1);
  Serial.print(F("Timestamp: "));
  Serial.print(integer_time[2]); Serial.print(':');
  Serial.print(integer_time[1]); Serial.print(':');
  Serial.print(integer_time[0]); Serial.print(", ");
  Serial.print(integer_time[5]); Serial.print('/');
  Serial.print(integer_time[4]); Serial.print('/');
  Serial.print(integer_time[6]); Serial.println();

  //----------------turn on thermometers--------------
  sht31.begin(0x44);
  //sht32.begin(0x45);
  hdc1080.begin(0x40);

  //----------------wrap-up---------------------------
  Serial.println(F("setup completed"));
  delay(3000);
}

//----------------------------------------------------------------------------------------
//----------------------------------------------------------------------------------------

void loop()
{
  digitalWrite(VREF_EN, HIGH);
  long toc = millis();
  acquire_data();  //Serial.println(millis() - toc);
  process_data();  //Serial.println(millis() - toc);
  //digitalWrite(VREF_EN, LOW);
  while ( millis() - toc < FREQUENCY - 100) {delay(10);}
  while( millis() - toc < FREQUENCY){;}
}

void acquire_data()
{
  digitalWrite(FAN_EN, HIGH); 
  // delay(FAN_INTERVAL);
  //digitalWrite(FAN_EN, LOW);  delay(2000);
  read_afe_data();
  read_pms_data();
  digitalWrite(FAN_EN, LOW);
}

void process_data()
{
  char nbuf[12];
  rtc_read_timestamp(1);
  int dy = integer_time[4];
  int mon = integer_time[5];
  int yr = integer_time[6];  
  if(mon < 10 && dy < 10){
    sprintf(nbuf, "F%d0%d0%d.txt", yr, mon, dy);
  }else if(mon < 10 && dy >= 10){
    sprintf(nbuf, "F%d0%d%d.txt", yr, mon, dy);
  }else if(mon >= 10 && dy < 10){
    sprintf(nbuf, "F%d0%d%d.txt", yr, mon, dy);
  }
  File myFile = SD.open(nbuf, FILE_WRITE);
  //myFile.print(nbuf);
  Serial.print(nbuf);
  Serial.print(": ");
  for (int i = 0; i < DATA_ARRAY_SIZE; i++) {
    Serial.print(data_array[i]);
    myFile.print(data_array[i]);
    if(i < DATA_ARRAY_SIZE - 1){
      Serial.print(',');
      myFile.print(',');
    }
    else{
      Serial.println();
      myFile.println();
    }
  }
  myFile.close();
}

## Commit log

2017-08-04 eeprom readout after writing in debug mode fixed
    [wxcube_main.ino]
2017-08-08 rewrite of esp_main.ino
    Ready to connect to the atm_main.ino. Communications passed to the esp by the atmega are used to communicate a parameter datum, send a post consisting of a collection of parameter data, or query the 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
    Acceptable communications to the ESP (see lines 113 - 139) are of the format [t 23.45x] where 't' is the command character (in this case, set the temperature value), followed by a space, then up to 2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
2017-08-19 adding circuit board files
    three WeatherCube circuit boards, plus two boot rig boards; EagleCAD schematic and board layout files for each
    [LMP9100_v2.3.brd, LMP9100_v2.3.sch, boot_rig_atmega.brd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]
2017-08-22 fixed intervals, still having issues reading data?
    [wxcube_main.ino]
2017-08-22 fixed sensor saving
    Still getting nans in some stds and the thermometers
    [wxcube_main.ino]
2017-08-29 uploading hourly to AWS
    also added 10 tries for wifi posting, still need to take care of case where there is partial posting
2017-09-06 corrected voltage, fixed temp readings, etc
    [esp_main.ino, wxcube_main.ino]
2017-09-06 fixed initial loop counter saving
    [wxcube_main.ino, wxcube_main_continuousmeasurements.ino]
2017-09-14 reorganized hardware and software
    [LMP9100_v2.3.brd, LMP9100_v2.3.sch, boot_rig_atmega.brd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]
2018-01-31 adding fix for vref + Chris code cleanup
    [wxcube_main.ino]
2018-02-18 making git file directory openable in arduino
2018-03-03 added PM sensor code
2018-03-21 Update zonda.ino
    Fixed buffer overflow, increased available RAM. Should be ready for field use.
    [zonda.ino]
2018-03-23 Added F macros to some print statements, moved two errant brackets
2018-03-23 Added missing close paren
    [wxcube_main.ino]
2018-06-08 starting powertrain
    [mistral_powertrain_breakout0.brd, mistral_powertrain_breakout0.sch]
2018-07-12 board updates
    [mistral_humtemp_breakout0.brd, mistral_humtemp_breakout0.sch, mistral_powertrain_breakout0.brd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]

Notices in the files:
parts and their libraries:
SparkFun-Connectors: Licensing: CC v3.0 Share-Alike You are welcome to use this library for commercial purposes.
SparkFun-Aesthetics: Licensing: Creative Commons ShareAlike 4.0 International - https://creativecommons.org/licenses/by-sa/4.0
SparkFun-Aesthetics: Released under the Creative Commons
